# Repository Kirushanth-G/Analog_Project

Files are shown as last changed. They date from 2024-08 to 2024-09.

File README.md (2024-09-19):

# Weighing Scale with Load Cell and Instrumentation Amplifier

This project is a high-precision weighing scale using a load cell sensor, a custom analog circuit employing an instrumentation amplifier with ADA4062-2BRZ op-amps, and a microcontroller for data acquisition and display. The system also includes a custom-designed PCB and a linear power supply for noise-free operation.

## Table of Contents

- [Overview](#overview)
- [Features](#features)
- [Hardware Components](#hardware-components)
- [Circuit Description](#circuit-description)
- [Power Supply Design](#power-supply-design)
- [Microcontroller and ADC](#microcontroller-and-adc)
- [PCB Design](#pcb-design)
- [Enclosure](#enclosure)
- [Usage](#usage)

## Overview

This weighing scale project integrates a load cell, signal conditioning circuit using ADA4062-2BRZ op-amps, and a microcontroller (ESP32 WROOM 32E) for high-accuracy weight measurement. The project features a linear power supply and custom PCB. The system also utilizes a 16-bit ADS1115 ADC for precise analog-to-digital conversion.
Overview

## Features

- High-precision weight measurement using a load cell.
- ADA4062-2BRZ-based instrumentation amplifier for high gain and low noise.
- Integrated voltage adder for offset correction.
- Linear power supply for stable +12V and -12V, minimizing noise.
- Digital weight display using a 16x2 LCD.
- Custom PCB design for the analog circuitry and power management.
- 3D-printed enclosure for housing the electronics.

## Hardware Components

- **Load Cell**: Measures the weight.
- **ADA4062-2BRZ Instrumentation Amplifier**: Amplifies the differential signal from the load cell with a gain of 401.
- **ADS1115 16-bit ADC**: High-precision analog-to-digital conversion.
- **ESP32 WROOM 32E**: Microcontroller for data processing and display control.
- **Custom PCB**: Contains the amplifier circuit and power management.
- **Linear Power Supply PCB**: Provides +12V, -12V, and +5V DC.
- **16x2 LCD Display**: For displaying the measured weight.

## Circuit Description

### Instrumentation Amplifier

The heart of this project is an instrumentation amplifier based on three ADA4062-2BRZ operational amplifiers configured to achieve a gain of 401. Key features of the amplifier include:
- **High Input Impedance**: Prevents current draw from the load cell, preserving accuracy.
- **Differential Input**: Amplifies only the voltage difference, rejecting common-mode noise.
- **Low Drift and Noise**: Ensures precision even with small load cell signals and environmental variations.
- **Offset Correction**: A voltage adder circuit corrects any offset voltage for improved accuracy.
Instrumentatin_amp

### Why an Instrumentation Amplifier?

1. **High Input Impedance**: Ensures minimal loading on the load cell, preserving measurement accuracy.
2. **Noise Rejection**: Differential input cancels out noise common to both input terminals.
3. **Precision**: Low drift and low offset ensure stable readings under varying environmental conditions.

## Power Supply Design

The weighing scale is powered by a dual supply (+12V and -12V), designed using a center-tapped transformer:
- **AC Conversion**: A 15V AC supply is generated using a step-down transformer.
- **Rectification**: A full-bridge rectifier converts the AC supply to DC, and a 1000uF capacitor smooths the output.
- **Voltage Regulation**: +12V is regulated using an L7812 IC, and -12V is regulated using an L7912 IC.
- **Additional 5V Output**: A +5V regulated output is provided using an L7805 IC for the microcontroller and peripherals.
- **Noise Filtering**: 10uF/25V and 0.1uF capacitors are used to filter ripples and high-frequency noise.

## Microcontroller and ADC

The digital aspect of the system is handled by:
- **ESP32 WROOM 32E Module**: Reads the output from the ADC and controls the display.
- **ADS1115 ADC**: Converts the amplified load cell output into a digital signal for the ESP32. The high-resolution 16-bit ADC ensures precise weight measurements.
- **Display**: A 16x2 LCD is used to show the real-time weight.

### Software

1. Install the required libraries for ESP32 and ADS1115.
2. Upload the code to the ESP32 WROOM 32E.

## PCB Design

The custom PCB integrates:
- The instrumentation amplifier circuit.
- Power management system (linear regulators and filtering components).
- Connections for the microcontroller, ADC, load cell, and display.
- Design files and schematics can be found in the `PCB` folder.

### Power supply schematic
Powersupply

### Amplifier schematic
Amplifier

### MCU schematic
MCU

## Enclosure

A custom 3D-printed enclosure houses the entire system, providing protection and ease of use. The enclosure design files can be found in the `Enclosure_solidworks` folder.

Enclosure1

### Prototype
Prototype

## Usage

### Calibration

1. Connect the load cell to the PCB.
2. Place a known weight on the load cell platform.
3. Use the calibration script provided to set the zero offset and calibration factor.

### Weighing

1. Power on the system.
2. Place an object on the load cell.
3. The weight will be displayed on the LCD screen in real time.

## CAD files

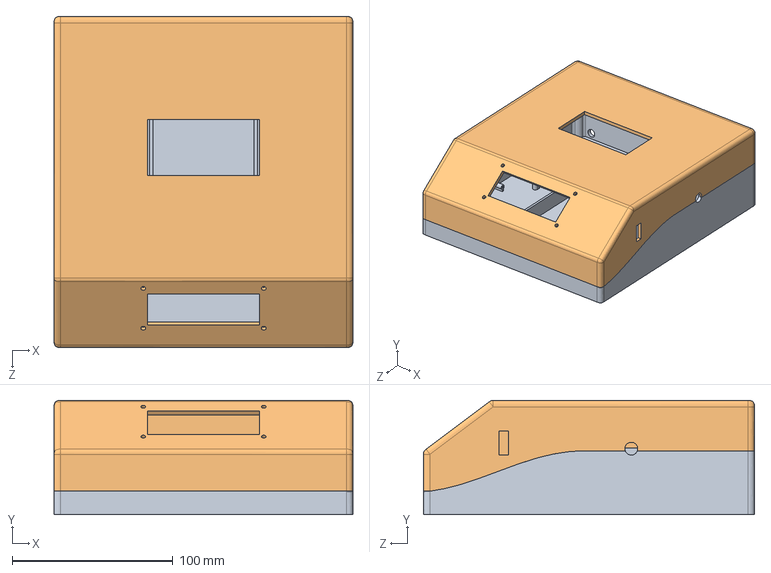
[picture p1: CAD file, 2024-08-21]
Enclosure_solidworks/balance assem.SLDASM
186.0 x 71.0 x 206.0 mm
upper1
lower1

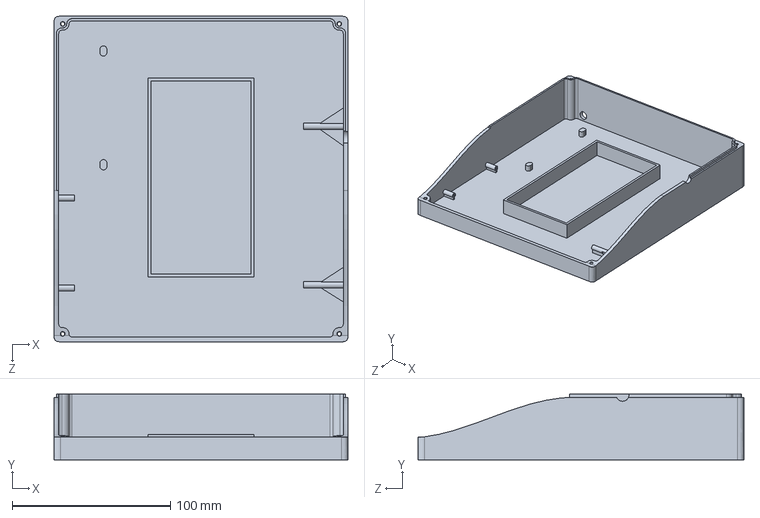
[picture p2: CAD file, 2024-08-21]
Enclosure_solidworks/lower1.SLDPRT
186.0 x 41.5 x 206.0 mm

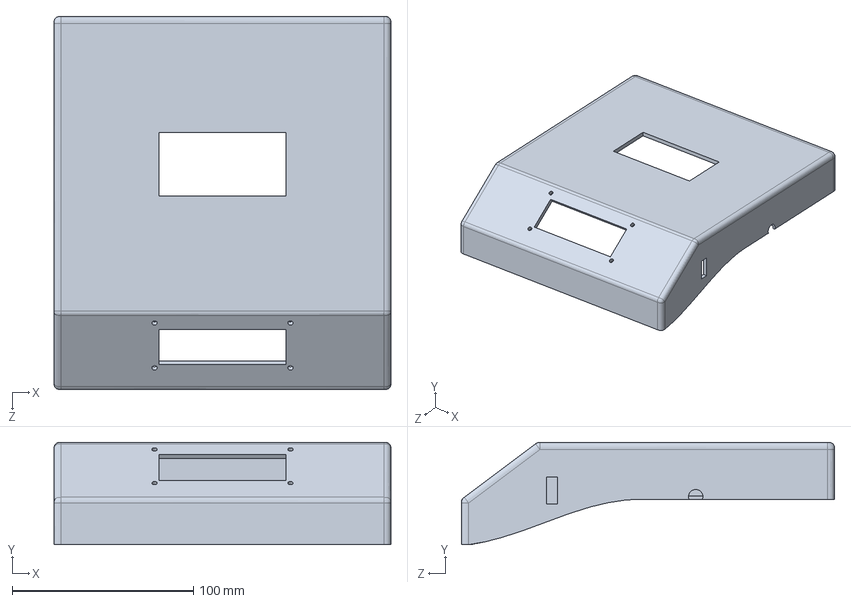
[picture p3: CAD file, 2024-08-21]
Enclosure_solidworks/upper1.SLDPRT
186.0 x 56.5 x 206.0 mm

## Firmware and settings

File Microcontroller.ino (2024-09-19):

// include the library code:
#include <LiquidCrystal.h>
#include <Wire.h>
#include <Adafruit_ADS1015.h>

Adafruit_ADS1115 ads(0x48);
float Voltage = 0.0;
float Weight;

// initialize the library with the numbers of the interface pins
LiquidCrystal lcd(19, 23, 18, 17, 16, 15);

void setup(void) 
{
Serial.begin(9600); 
ads.begin();
// set up the LCD's number of columns and rows:
lcd.begin(16, 2);
lcd.clear();
lcd.setCursor(1, 0);
// Print Error message on the LCD.
lcd.print("Welcome to");

lcd.setCursor(3, 1);
// print the ADC value:
lcd.print("Thiruchitrampalam electronics");
}

void loop(void) 
{
int16_t adc0;
adc0 = 1*ads.readADC_SingleEnded(0);
Voltage = (adc0 * 0.1875)/1000;

if(Voltage <= 5.0){
  Weight = (map((adc0 * 1.875), 2100, 10100, 0, 10000))/1000.0;

  lcd.clear();
  lcd.setCursor(0, 0);
  // Print Caption on the LCD.
  lcd.print("Weight is: ");
  // set the cursor to column 0, line 1
  lcd.setCursor(0, 1);
  // print the ADC value:
  lcd.print(Weight, 3);

  // set the cursor to column 6, line 1
  lcd.setCursor(6, 1);
  // print Kg at the end:
  lcd.print("Kg");
  Serial.print("adc value: ");
  Serial.print(adc0);
  Serial.print("  Voltage value: ");
  Serial.println(Voltage);


}

else{
  lcd.clear();
  lcd.setCursor(1, 0);
  // Print Error message on the LCD.
  lcd.print("Weight is more");
  
  lcd.setCursor(3, 1);
  // print the ADC value:
  lcd.print("than 10 Kg");
}


// Serial.print("AIN0: "); 
// Serial.print(adc0);
// Serial.print("\tVoltage: ");
// Serial.print(Voltage, 7);
// Serial.print("\tWeight: ");
// Serial.println(Weight, 3); 
// Serial.println();

delay(500);
}
